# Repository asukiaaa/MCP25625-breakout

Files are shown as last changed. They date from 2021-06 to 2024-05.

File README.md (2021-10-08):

# MCP25625-breakout

A breakout board of MCP25625.

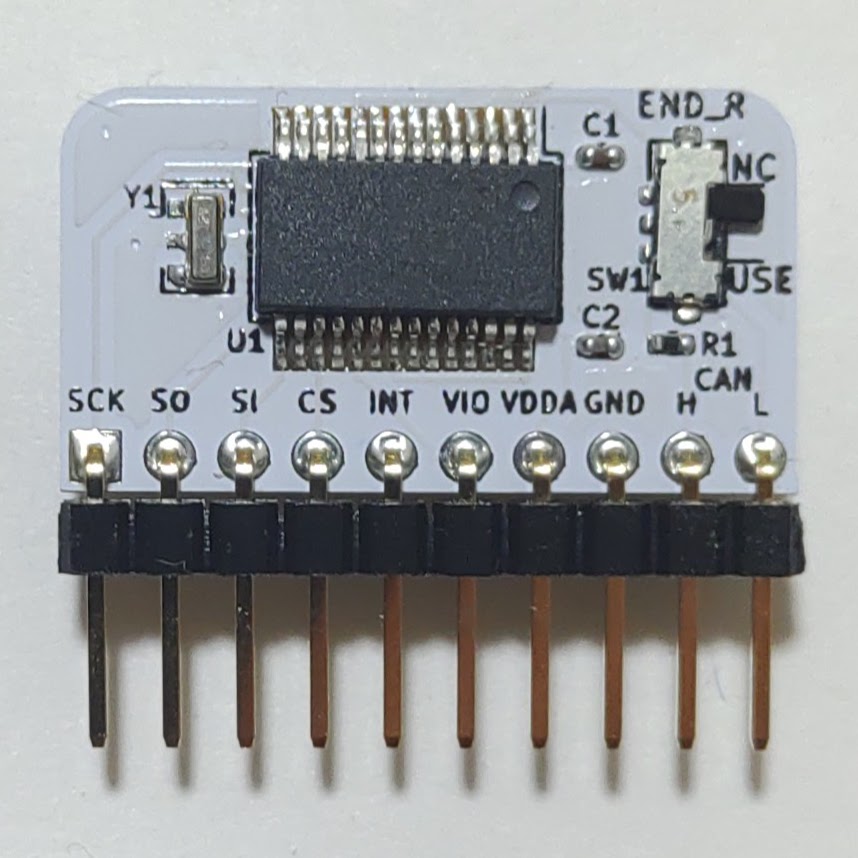
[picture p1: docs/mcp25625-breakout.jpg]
mcp25625-breakout


Schematic: [docs/mcp25625-breakout.pdf](docs/mcp25625-breakout.pdf)

## Components

- MCP25625 SSOP28
- 0.1uf 0402
- 22pf 0402
- 120 ohm 0402
- [slide switch smd](https://akizukidenshi.com/catalog/g/gP-13989/)
- [16MHz crystal](https://akizukidenshi.com/catalog/g/gP-02457/)

## Where to buy

[MCP25625-breakout](https://www.switch-science.com/catalog/7228/)

## License

MIT

## References

- [CanBusMCP2515-arduino](https://github.com/asukiaaa/CanBusMCP2515-arduino)
- [CANをArduinoで使ってみた](https://asukiaaa.blogspot.com/2021/07/canarduino.html)
- [製品紹介 MCP25625-breakout](https://asukiaaa.blogspot.com/2021/06/mcp25625-breakout.html)

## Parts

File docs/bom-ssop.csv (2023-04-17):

Reference | Quantity | Value | Url | Memo
C1 C2 | 2 | 0402 0.1u | https://www.digikey.jp/product-detail/ja/taiyo-yuden/EMK105BJ104KV-F/587-1226-1-ND/931003 | I don’t mind vendor if it support over 10V.
C3 C4 | 2 | 0402 22p |  | I don’t mind vendor if it support over 10V.
J1 | 1 | L pin header 01x10 | https://akizukidenshi.com/catalog/g/gC-01627/ | I don’t mind vendor.
R1 | 1 | 0402 120 | https://www.digikey.jp/product-detail/ja/yageo/RC0402JR-07120RL/311-120JRCT-ND/2827967 | I don’t mind vendor if it is equal or less than 5%.
R2 | 1 | 0402 10k |  | I don’t mind vendor if it is equal or less than 5%.
SW1 | 1 | SW_Slide_with_cover | https://www.mouser.com/ProductDetail/Alps-Alpine/SSAJ120100?qs=35GPJvxY%252Bl5mRNwFoBrl2g%3D%3D
U1 | 1 | MCP25625-x-SS | https://www.digikey.jp/product-detail/ja/microchip-technology/MCP25625T-E-SS/MCP25625T-E-SSCT-ND/9450517
Y1 | 1 | Crystal 16MHz | https://www.digikey.jp/product-detail/ja/epson/FA-238-16-0000MB-K3/SER4046CT-ND/5175138

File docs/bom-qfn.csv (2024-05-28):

*Reference | *Manufacturer Part number | *QTY | *Original | Description | Purchase Link
C1 C2 |  | 2 | N | 0402 0.1u | https://www.digikey.jp/product-detail/ja/taiyo-yuden/EMK105BJ104KV-F/587-1226-1-ND/931003
C3 C4 |  | 2 | N | 0402 22p
J1 |  | 1 | N | L pin header 01x10 | https://akizukidenshi.com/catalog/g/gC-01627/
R1 |  | 1 | N | 0402 120
R2 |  | 1 | N | 0201 10k
SW1 |  | 1 | Y | SW_Slide_with_cover | https://www.mouser.com/ProductDetail/Alps-Alpine/SSAJ120100?qs=35GPJvxY%252Bl5mRNwFoBrl2g%3D%3D
U1 | MCP25625-x-ML | 1 | Y | MCP25625-x-ML | https://www.digikey.jp/ja/products/detail/microchip-technology/MCP25625-E-ML/4842804
Y1 | FA-238 16.0000M | 1 | Y | Crystal 16MHz | https://www.digikey.jp/product-detail/ja/epson/FA-238-16-0000MB-K3/SER4046CT-ND/5175138

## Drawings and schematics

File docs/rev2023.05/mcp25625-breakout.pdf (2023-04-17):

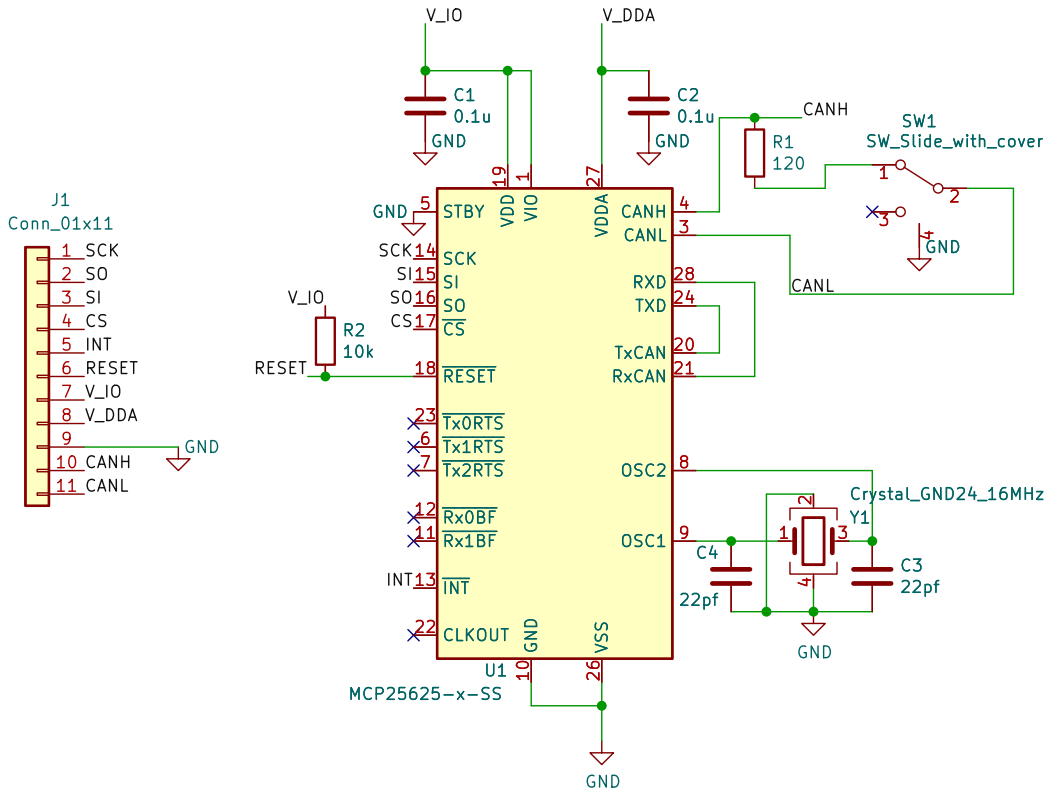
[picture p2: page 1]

Id: 1/1 Title: File: mcp25625-breakout.kicad_sch Sheet: / GND

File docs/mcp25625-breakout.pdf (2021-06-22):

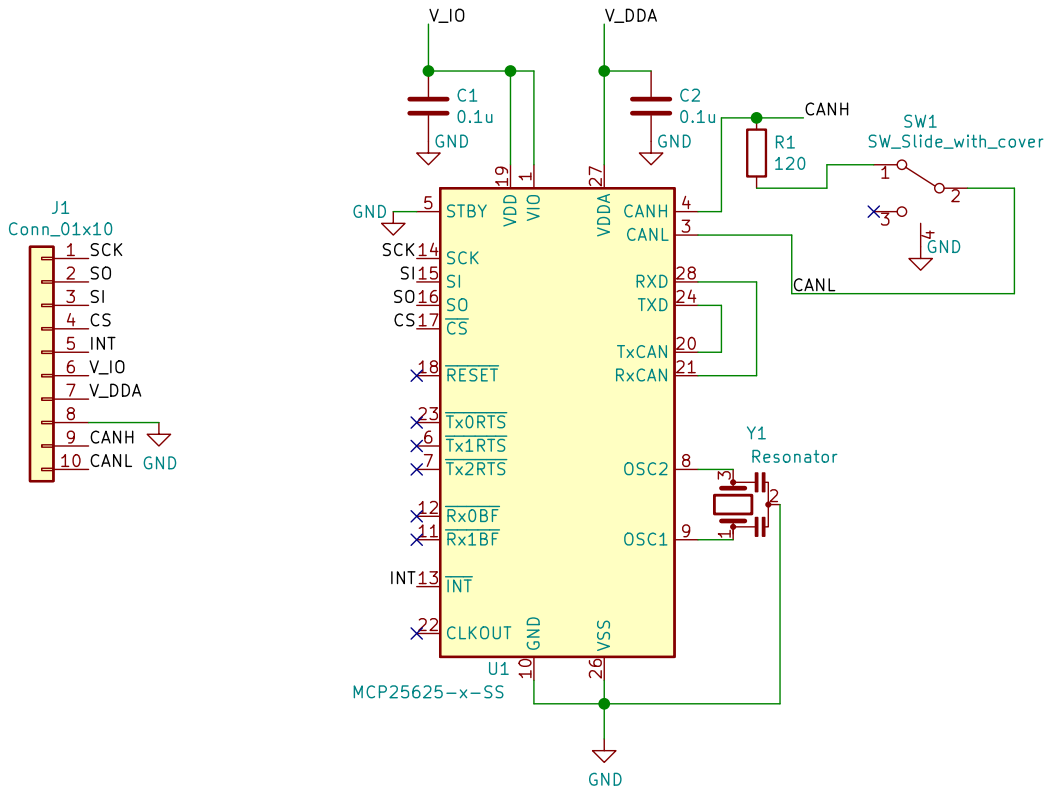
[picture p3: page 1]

File: mcp25625-breakout.sch Sheet: /
Id: 1/1 Title:

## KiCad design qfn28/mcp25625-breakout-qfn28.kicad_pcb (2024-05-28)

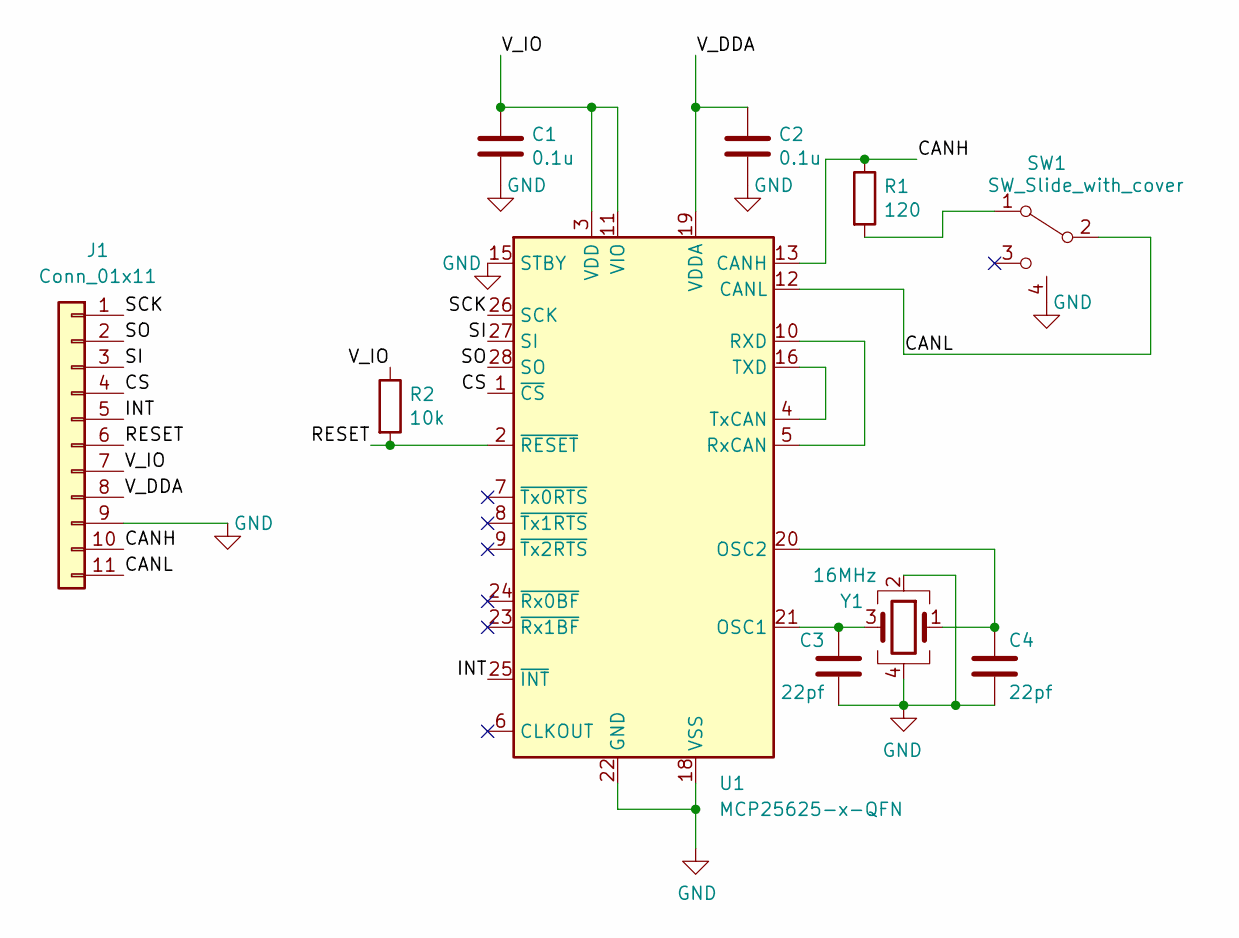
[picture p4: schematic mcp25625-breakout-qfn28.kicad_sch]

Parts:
C1, C2: 0.1u; C_0402_1005Metric
C3, C4: 22pf; C_0402_1005Metric
J1: Conn_01x11; PinHeader_1x11_P2.54mm_Vertical_witout_silk
R1: 120; R_0402_1005Metric
R2: 10k; R_0201_0603Metric
SW1: SW_Slide_with_cover; slide_switch_smd
U1: MCP25625-x-QFN; QFN-28-1EP_6x6mm_P0.65mm_EP4.25x4.25mm
Y1: 16MHz; Crystal_SMD_SeikoEpson_FA238-4Pin_3.2x2.5mm

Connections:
/CANH: J1.10, R1.1, U1.13 (CANH)
/CANL: J1.11, SW1.2 (B), U1.12 (CANL)
/CS: J1.4, U1.1 (~CS)
/INT: J1.5, U1.25 (~INT)
/RESET: J1.6, R2.2, U1.2 (~RESET)
/SCK: J1.1, U1.26 (SCK)
/SI: J1.3, U1.27 (SI)
/SO: J1.2, U1.28 (SO)
/V_DDA: C2.1, J1.8, U1.19 (VDDA)
/V_IO: C1.1, J1.7, R2.1, U1.3 (VDD), U1.11 (VIO)
GND: C1.2, C2.2, C3.2, C4.2, J1.9, SW1.4 (Cover), U1.15 (STBY), U1.18 (VSS), U1.22 (GND), Y1.2, Y1.4
unnamed: R1.2, SW1.1 (A)
unnamed: C3.1, U1.21 (OSC1), Y1.3
unnamed: C4.1, U1.20 (OSC2), Y1.1
unnamed: U1.5 (RxCAN), U1.10 (RXD)
unnamed: U1.4 (TxCAN), U1.16 (TXD)

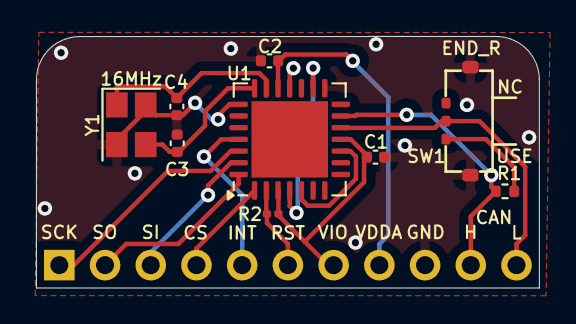
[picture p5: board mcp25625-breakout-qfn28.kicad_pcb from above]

Board: 2 copper layers, 27.9 x 14.0 mm, 10 parts (0 on the bottom side), 16 nets.

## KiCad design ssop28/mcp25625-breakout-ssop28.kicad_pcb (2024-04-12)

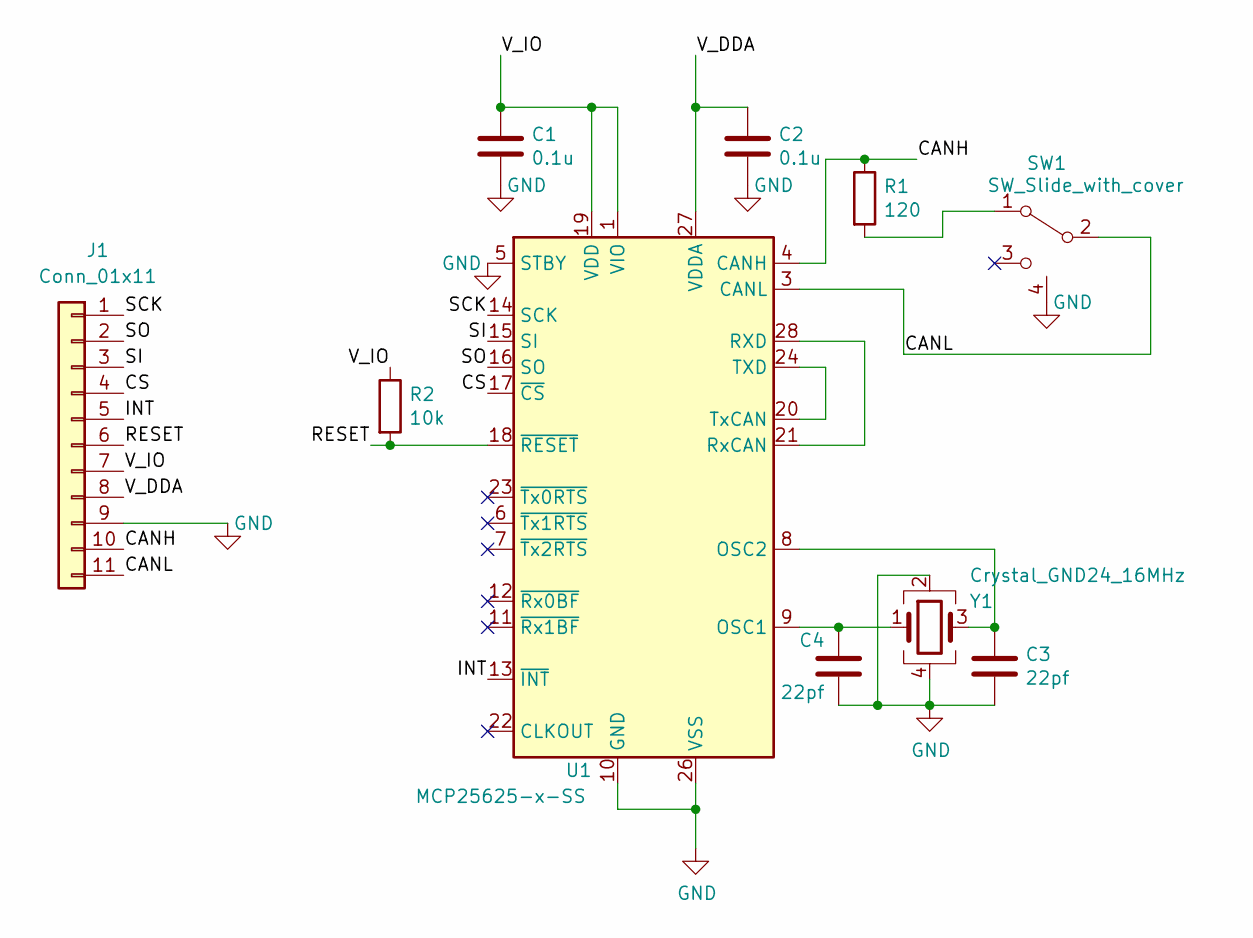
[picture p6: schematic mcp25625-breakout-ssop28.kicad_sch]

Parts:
C1, C2: 0.1u; C_0402_1005Metric
C3, C4: 22pf; C_0402_1005Metric
J1: Conn_01x11; PinHeader_1x11_P2.54mm_Vertical_witout_silk
R1: 120; R_0402_1005Metric
R2: 10k; R_0402_1005Metric
SW1: SW_Slide_with_cover; slide_switch_smd
U1: MCP25625-x-SS; SSOP-28_5.3x10.2mm_P0.65mm
Y1: Crystal_GND24_16MHz; Crystal_SMD_SeikoEpson_FA238-4Pin_3.2x2.5mm

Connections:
/CANH: J1.10, R1.1, U1.4 (CANH)
/CANL: J1.11, SW1.2 (B), U1.3 (CANL)
/CS: J1.4, U1.17 (~CS)
/INT: J1.5, U1.13 (~INT)
/RESET: J1.6, R2.2, U1.18 (~RESET)
/SCK: J1.1, U1.14 (SCK)
/SI: J1.3, U1.15 (SI)
/SO: J1.2, U1.16 (SO)
/V_DDA: C2.1, J1.8, U1.27 (VDDA)
/V_IO: C1.1, J1.7, R2.1, U1.1 (VIO), U1.19 (VDD)
GND: C1.2, C2.2, C3.2, C4.2, J1.9, SW1.4 (Cover), U1.5 (STBY), U1.10 (GND), U1.26 (VSS), Y1.2, Y1.4
unnamed: C3.1, U1.8 (OSC2), Y1.3
unnamed: C4.1, U1.9 (OSC1), Y1.1
unnamed: R1.2, SW1.1 (A)
unnamed: U1.20 (TxCAN), U1.24 (TXD)
unnamed: U1.21 (RxCAN), U1.28 (RXD)

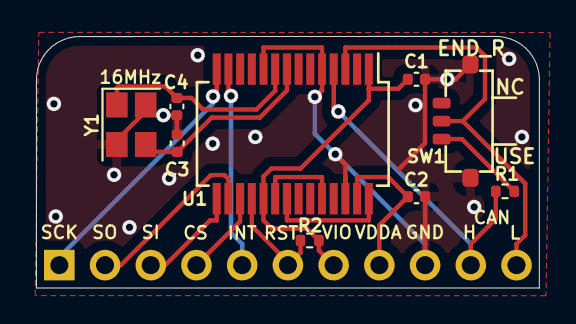
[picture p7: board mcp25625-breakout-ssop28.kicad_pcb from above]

Board: 2 copper layers, 27.9 x 14.0 mm, 10 parts (0 on the bottom side), 16 nets.

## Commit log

2021-06-06 Initial commit as Rev2021.06
    [mcp25625-breakout.dsn, mcp25625-breakout.kicad_pcb, mcp25625-breakout.sch]
2021-06-08 Fill again
    [mcp25625-breakout.kicad_pcb]
2021-06-20 Add bom and image in docs directory
    [bom.csv]
2021-06-22 Add pdf of schematic
2021-07-11 Add reset pad and 16MHz mems as rev2021.07
    [mcp25625-breakout.dsn, mcp25625-breakout.kicad_pcb, mcp25625-breakout.sch]
2021-10-08 Replace rezonator to crystal
    [bom.csv, mcp25625-breakout.kicad_pcb, mcp25625-breakout.sch]
2022-05-01 Apply KiCad6
    [mcp25625-breakout.kicad_pcb, mcp25625-breakout.kicad_sch, mcp25625-breakout.sch]
2022-05-01 Apply KiCad6 lib
    [mcp25625-breakout.dsn, mcp25625-breakout.kicad_pcb, mcp25625-breakout.kicad_sch]
2023-02-01 Change to not hand solder pad for crystal
    [mcp25625-breakout.kicad_pcb, mcp25625-breakout.kicad_sch]
2023-04-17 Add resistor between rst and vio as rev2023.05
    [bom.csv, mcp25625-breakout.kicad_pcb, mcp25625-breakout.kicad_sch]
2024-04-12 Put current project to ssop28 dir
    [mcp25625-breakout.dsn, mcp25625-breakout.kicad_pcb, mcp25625-breakout.kicad_sch]
2024-04-12 Rename project in ssop28 dir
    [mcp25625-breakout-ssop28.dsn, mcp25625-breakout-ssop28.kicad_pcb, mcp25625-breakout-ssop28.kicad_sch]
2024-04-12 Add qfn28 project as rev2024.05
    [bom-qfn.csv, bom-ssop.csv, mcp25625-breakout-qfn28.dsn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]
2024-05-28 Update bom for qfn package
    [bom-qfn.csv]
2024-05-28 Show 16MHz silk on pcb for qfn
    [mcp25625-breakout-qfn28.kicad_pcb]
